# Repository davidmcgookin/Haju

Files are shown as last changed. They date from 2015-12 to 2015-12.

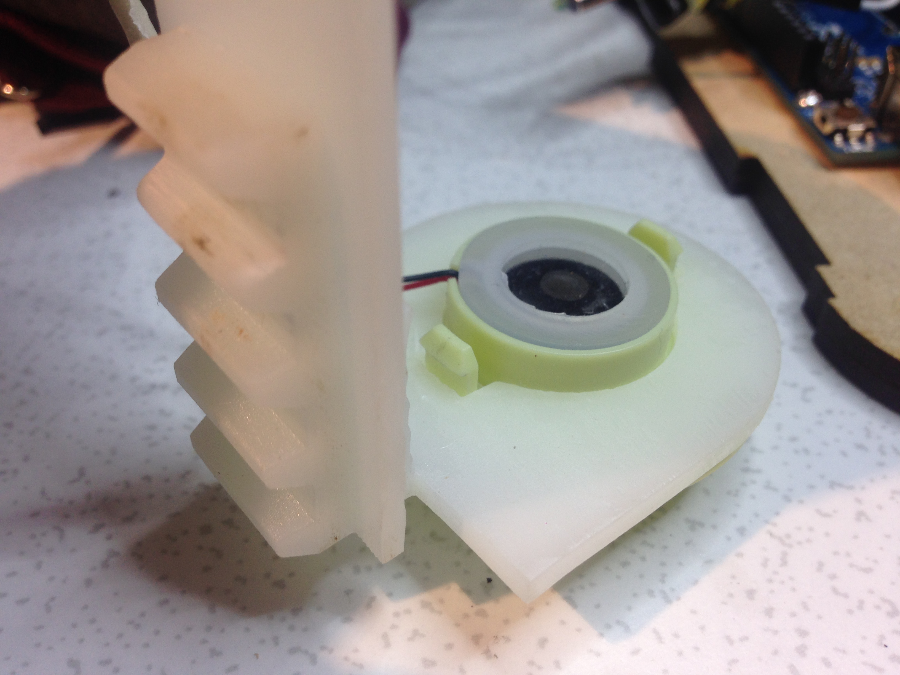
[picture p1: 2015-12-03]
illustrative_images/IMG_2800.JPG

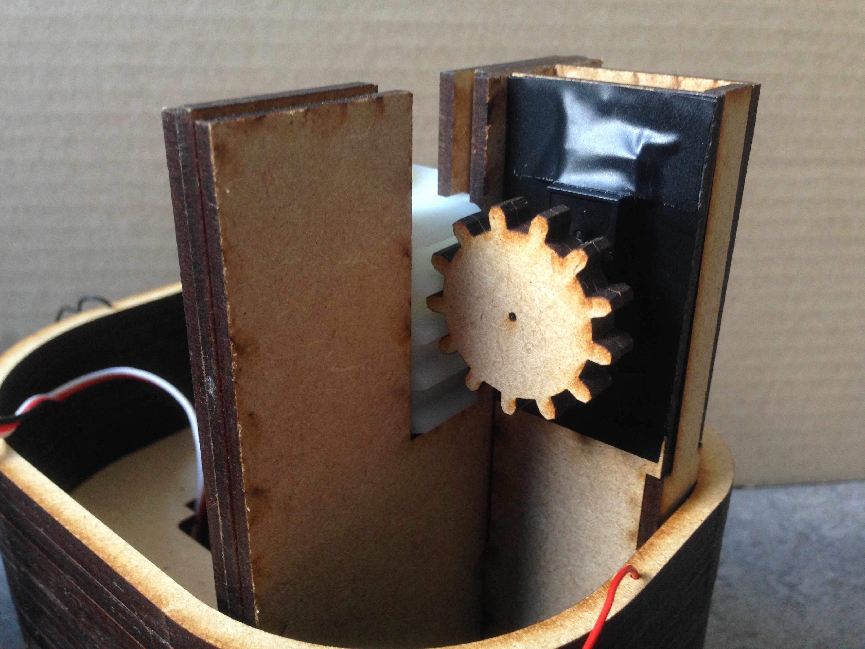
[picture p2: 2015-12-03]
illustrative_images/IMG_2740.JPG

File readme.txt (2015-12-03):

This folder contains the files needed to create a Haju smell device

You will need a set of components

An Arduino UNO
2 x microservos (one continuous type and another linear type)
1 push to close switch
A 220kOhm resistor
an NPN transistor
A USB desk humidifier (e.g. A Douself Mini Portable Magic Wand Stick (http://www.amazon.co.uk/gp/product/B00OUSHI2G) But any similar 5V humidifier can be made to work (with more or less effort)
microUSB cable (probably can be used from the humidifier)
5V battery to run the humidifier

A circuit diagram is is provided to illustrate how the electronic components should be combined. An Arduino sketch is provided to act as control software. This receives commands via the Arduino serial monitor to control scents from the device.

The case and most of the supports to hold the smell container, ratchet for the humidifier etc. are CNC'd, and are provided in adobe illustrator format.

The ratchet and smell container are 3D printed and provided in Rhino compatible files.

Full details on building the case are forthcoming, but the enclosed images should help to illustrate how the device goes together.

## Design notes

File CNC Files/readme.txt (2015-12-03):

This folder contains Adobe Illustrator files to support the creation of the case and the supports for the stepper motors using a CNC machine. 

case.ai contains the drawings to create the enclosure of the device.

cogs.ai contains the components to support and construct the humidifier mechanism

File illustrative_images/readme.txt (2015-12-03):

This folder contains images that should help put the device together.

These show how the ultrasonic humidifier fits into the ratchet. How the switches and servos are aligned in the case.

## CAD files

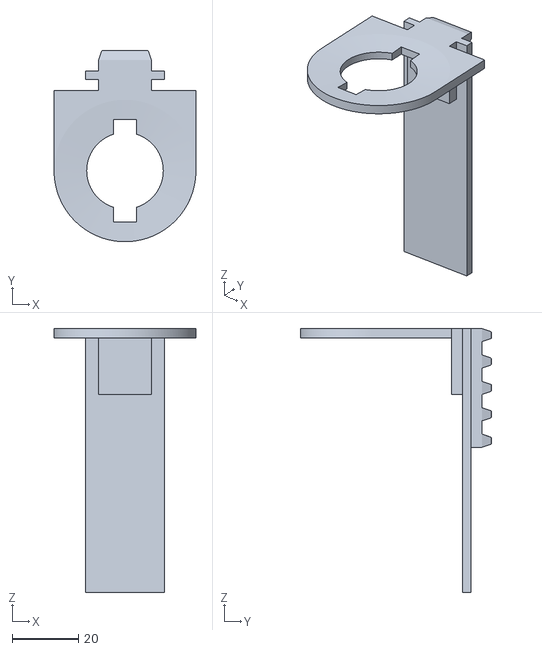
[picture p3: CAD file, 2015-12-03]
3D Printing Files/smell bottle/linear piece.stl
43.0 x 58.0 x 80.0

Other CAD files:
3D Printing Files/smell bottle.3dm

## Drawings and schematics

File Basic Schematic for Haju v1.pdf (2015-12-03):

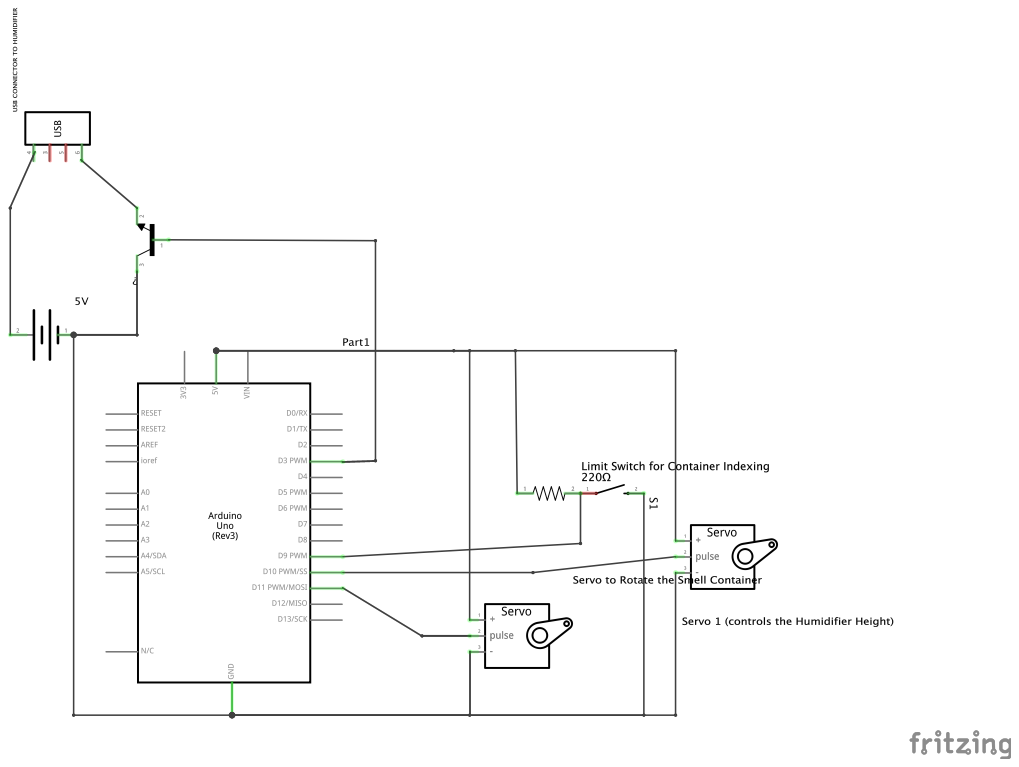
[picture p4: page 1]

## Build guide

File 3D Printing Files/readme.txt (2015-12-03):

This folder contains the 3D printing files for the Olfactory container, and the ratchet to hold and support movement of the Humidifer device.

You may need to adjust the ratchet aperture to accomodate a different humidifier 

The container can be completed by cutting drinking straws to 5cm, and filling with cigarette filter material. We have found this to be a good fibre to draw fluid up towards the humidifier.

smell_bottle.3dm is the Rhino model for the smell bottle and the ratchet for moving the humidifier components. The folder Smell Bottle contains stl files sutable for each component part to be printed.

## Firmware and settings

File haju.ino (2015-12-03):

/**
 * Haju Source Code
 * Version 1.0
 * David McGookin & Dariella Escobar
 * david.mcgookin@aalto.fi
 * 
 * (c) Aalto University 2015
 * 
 * This software is licensed under the GNU GPL v3 license
 * http://www.gnu.org/copyleft/gpl.html
 * 
 * USAGE
 * This code should be uploaded onto the Arduino.
 * Commands are sent over a serial connection in the form
 * <CMD><BIN>X
 * Where <CMD> is the command code (currently d to dispense a smell and r to rotate the fragrance bin without dispensing a smell)
 * <BIN> is the fragrance bin <CMD> applies to. Bins are numbered in accending order clockwise. Starting at 1 (the largest bin)
 * X is the terminator for the command
 * E.g. d3X (will dispense the scent in bin 3.
 * 
 */


#include <Bounce2.h>


//Codes used to start and stop the rotational servo. Note these are codes not angles
#define ROTATIONAL_SERVO_START 80
#define ROTATIONAL_SERVO_STOP 90

//max command length
#define CMD_LENGTH 3
//the terminator command
#define CMD_TERMINATOR 'x'


#include <Servo.h>    // include Servo library
#include <Bounce2.h>
#include <stdlib.h>

Servo piezoServo;     // create servo object to control small servo 
Servo rotationalServo;       // create servo object to control big servo 

//holds the last time we checked for the limitSwitch. Doing this to avoid calling delay. 
unsigned long lastMilliSecCheck;
int piezoPinOut =3;
int limitSwitchPinIn = 9;

int commandCode;

//The last fragrance bin that we passed by
int lastFragranceBin;

//the number of the bin we are searching for. 
int targetBin;


void setup() {
  // put your setup code here, to run once:
  Serial.begin(9600);
  piezoServo.attach(10);
  rotationalServo.attach(11);
  pinMode(piezoPinOut, OUTPUT);
  pinMode(limitSwitchPinIn, INPUT);


  //set the piezoServo
  piezoServo.write(0);


  //setup the logging to know what bin we are at.
  lastFragranceBin=1;// set to be water initially

}

void loop() {
  // put your main code here, to run repeatedly:
  //int state =  false;
  //char inputString[2];
  char cmd;
  int binIndex;

   if (readCommand(&cmd, &binIndex)) { // If data is available to read, get the command char
    Serial.println("HAVE CMD");
    switch(cmd){


    case 't': //test routine
      digitalWrite(piezoPinOut, HIGH);
      delay (5000);
      digitalWrite(piezoPinOut, LOW);
      break;
    case 'r':
      //reset the smell device
      lastFragranceBin = binIndex;
      locateFragranceBin(1);
      break;


    case 'd':
      if(binIndex > 1 && binIndex < 8){ // Scents are numberd. 0 is the water 1..5 are available for scents
         //targetBin = commandCode;
        locateFragranceBin(binIndex); //go to the bin with the desired smell
     
        Serial.println("DISPENSING VAPOUR");
        delay(3000);
        dispenseVapour();
        locateFragranceBin(1); //go to the water bin
      } 
      break;

    default:
      Serial.println("Invalid Command Provided");
      break;
  }
}
}

  

/* Causes the system to release the vapour of the currently selected reservoir
 
 */
 void dispenseVapour(){
     piezoServo.write(90);            // small servo motor rotates down
      digitalWrite (piezoPinOut, HIGH);  // turn piezo ON
       delay (5000);                   // spray out water to clean piezo
                        
       digitalWrite(piezoPinOut, LOW);    // turn piezo OFF
        piezoServo.write(0);           // small servo motor rotates back up
       delay (1000);                   // wait one second
  
  }


void locateFragranceBin(int binID){
   //start the servo running
        rotationalServo.write(80);
       delay (200);  
      do{
        bool switchActivated  = checkSwitchState();
      
       if(switchActivated){
          updateLastFragranceBin();
          Serial.println("SWITCH ACTIVATED");
        Serial.print("Last Seen Fragrance Bin was: ");
        Serial.println(lastFragranceBin);
       }
        }while(binID != lastFragranceBin);


  rotationalServo.write(90);
  
}


  void updateLastFragranceBin(){
       lastFragranceBin = lastFragranceBin+1;
       if(lastFragranceBin == 8){ //We have 7 bins numbered 0..6. Reset if we get to 7.
          lastFragranceBin = 1;
        }
       }
  
bool checkSwitchState(){
  bool currentSwitchState = digitalRead(limitSwitchPinIn);
  Serial.print(currentSwitchState);
  
  unsigned long  currentTime = millis();
  unsigned long deltaSinceLastActive = currentTime - lastMilliSecCheck;
  
  if (currentSwitchState == false && deltaSinceLastActive > 300){ //we put a check on the returning of true to avoid the switch staying active between calls
                                                                  //600 is hacked but seems to be a good number
                                                                  //the false here is the way we wired the circuit. It is true when open and false when closed. But returns true when activated and false otherwise!
                                                                    
      Serial.println(deltaSinceLastActive);
      lastMilliSecCheck = currentTime;
      return true;
  }else{
    return false;
  }
  }


//reads a command from the serial port. Returns false if there is no valid command or true if there is.
//Iff true, cmd and fragranceBin are filled in
 bool readCommand(char *cmd, int*fragranceBin){
  bool haveValidCommand = false;
  int charsRead = 0;
  bool haveCommandTerminator = false;
  char commandStr[CMD_LENGTH];
 
  for(int i = 0; i < CMD_LENGTH; i++){
   commandStr[i] = '?';
  }
 
  if(Serial.available()>=3){ //there are 3 characters in a command
    while(!haveCommandTerminator && charsRead < CMD_LENGTH){
      commandStr[charsRead] = char(Serial.read());
      //Serial.print(commandStr);
      if(commandStr[charsRead] == CMD_TERMINATOR){
      
        //We read the terminator command
        haveCommandTerminator = true;
      }
      charsRead++;
        
    }

  if(haveCommandTerminator && charsRead == CMD_LENGTH){ // We have a valid command
    haveValidCommand = true;
    *cmd = commandStr[0];
    *fragranceBin = commandStr[1] - '0';
  }
  }
  return haveValidCommand; 
  
 }
